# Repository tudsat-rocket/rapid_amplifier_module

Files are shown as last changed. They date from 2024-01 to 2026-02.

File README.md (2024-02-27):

# FRoDo Amplifier Module
this module is meant to be a general-purpose amplifier which is going to be used for all analogue sensors which will be in the rocket, those include the WIKA pressure sensors as well as the fancy-fins strain gauges.

## Description
The main function of the module is to amplify signals with low voltage levels that are too small to be useful for our ADCs. Therefore the board has two sides with solder pads, one to connect to the IO board and one to connect to a sensor. The layout is designed in a way, that the sensor side is compatible with the WIKA TPR-Flex PCBs.

## Features
* Selectable gain (1-1000) -> the selection of RG1 will determine the gain (G = 1 + 49,4kOhm/RG)
* selectable offset -> output offset can either be 0V or Vcc/2
* Breakaway mounting holes
## Connections
### To IO-Board:
Connects the amplifier module with the IO-Board with the following pins:
* u+  ->  positive supply voltage (3-36V)
* u-  ->  gnd as "neg" supply voltage (only use in single supply mode) | reference for the output signal.
* o+  ->  amplified signal, references gnd (u-)
* ref  ->  selected reference signal (0V or Vcc/2) can be used to get additional information (e.g. detect noise on supply line(?))

### To sensor:
Connects the amplifier module with the Sensor with the following pins:
* u+  -> positive supply voltage (filtered supply voltage)
* u-  -> neg. supply voltage (gnd)
* s+  -> positive signal
* s-  -> negative signal

## User guideline:
The Gain resistor (RG1) must be chosen in a way that the expected maximum amplified voltage is lower than 4.85V (5V - 0.15V) and the expected minimum amplified voltage is higher than 0.1V if a smaller (or negative) output voltage is expected the solder jumper for the reference voltage needs to be connected to 3 to set an output shift.
Only if the connected sensor is expected to output a signal which exclusively results in an output signal that is in the above given values, can the reference solder jumper be set to 1.

The above-given adjustments are necessary as the IO module is only able to read values between 0V and 5V. A higher Input voltage can be used if the connected sensor needs a supply voltage which exceeds 5V. The amplified signal then still needs to be smaller than the given 4.85V.

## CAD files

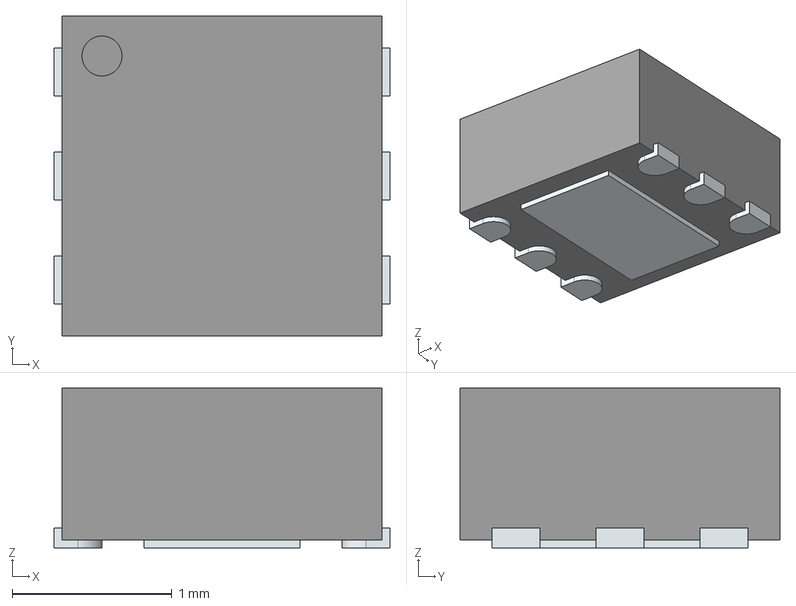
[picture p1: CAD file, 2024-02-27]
LDFM33PVR/3D/LDFM33PVR.stp
2.10 x 2.00 x 1.00 mm
ThermalPin
PinsArrayLR

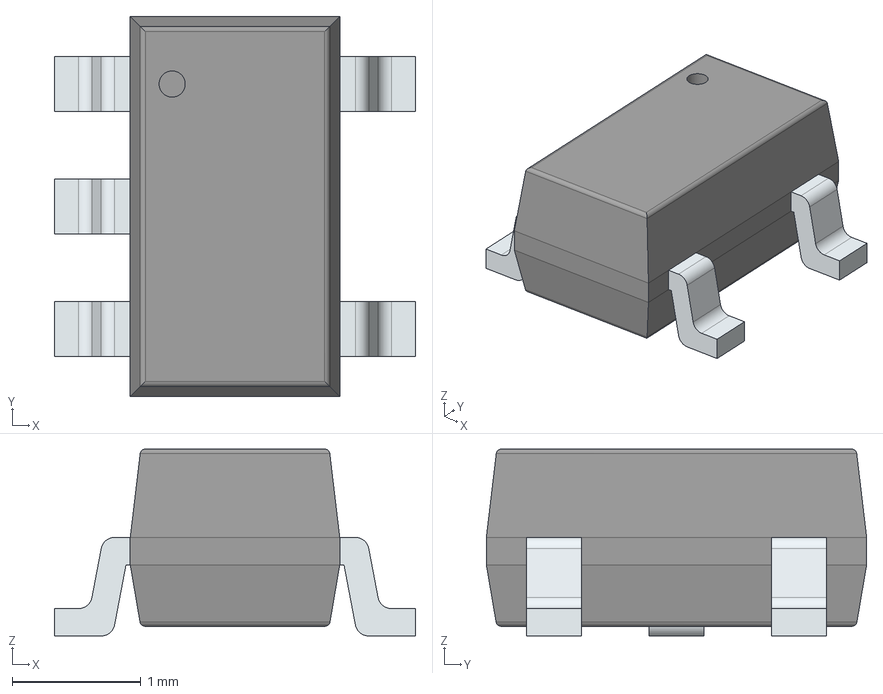
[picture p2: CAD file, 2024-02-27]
MCP3221A5T-I_OT/3D/MCP3221A5T-I_OT.stp
2.80 x 2.95 x 1.45 mm
PinsArrayL
PinsArrayR

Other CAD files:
LDFM33PVR/Allegro/son65p200x200x100-7n-d.psm
LDFM33PVR/DEHDL/ldfm33pvr/chips/chips.prt
MCP3221A5T-I_OT/Allegro/sot95p280x145-5n.psm
MCP3221A5T-I_OT/DEHDL/mcp3221a5t_i_ot/chips/chips.prt

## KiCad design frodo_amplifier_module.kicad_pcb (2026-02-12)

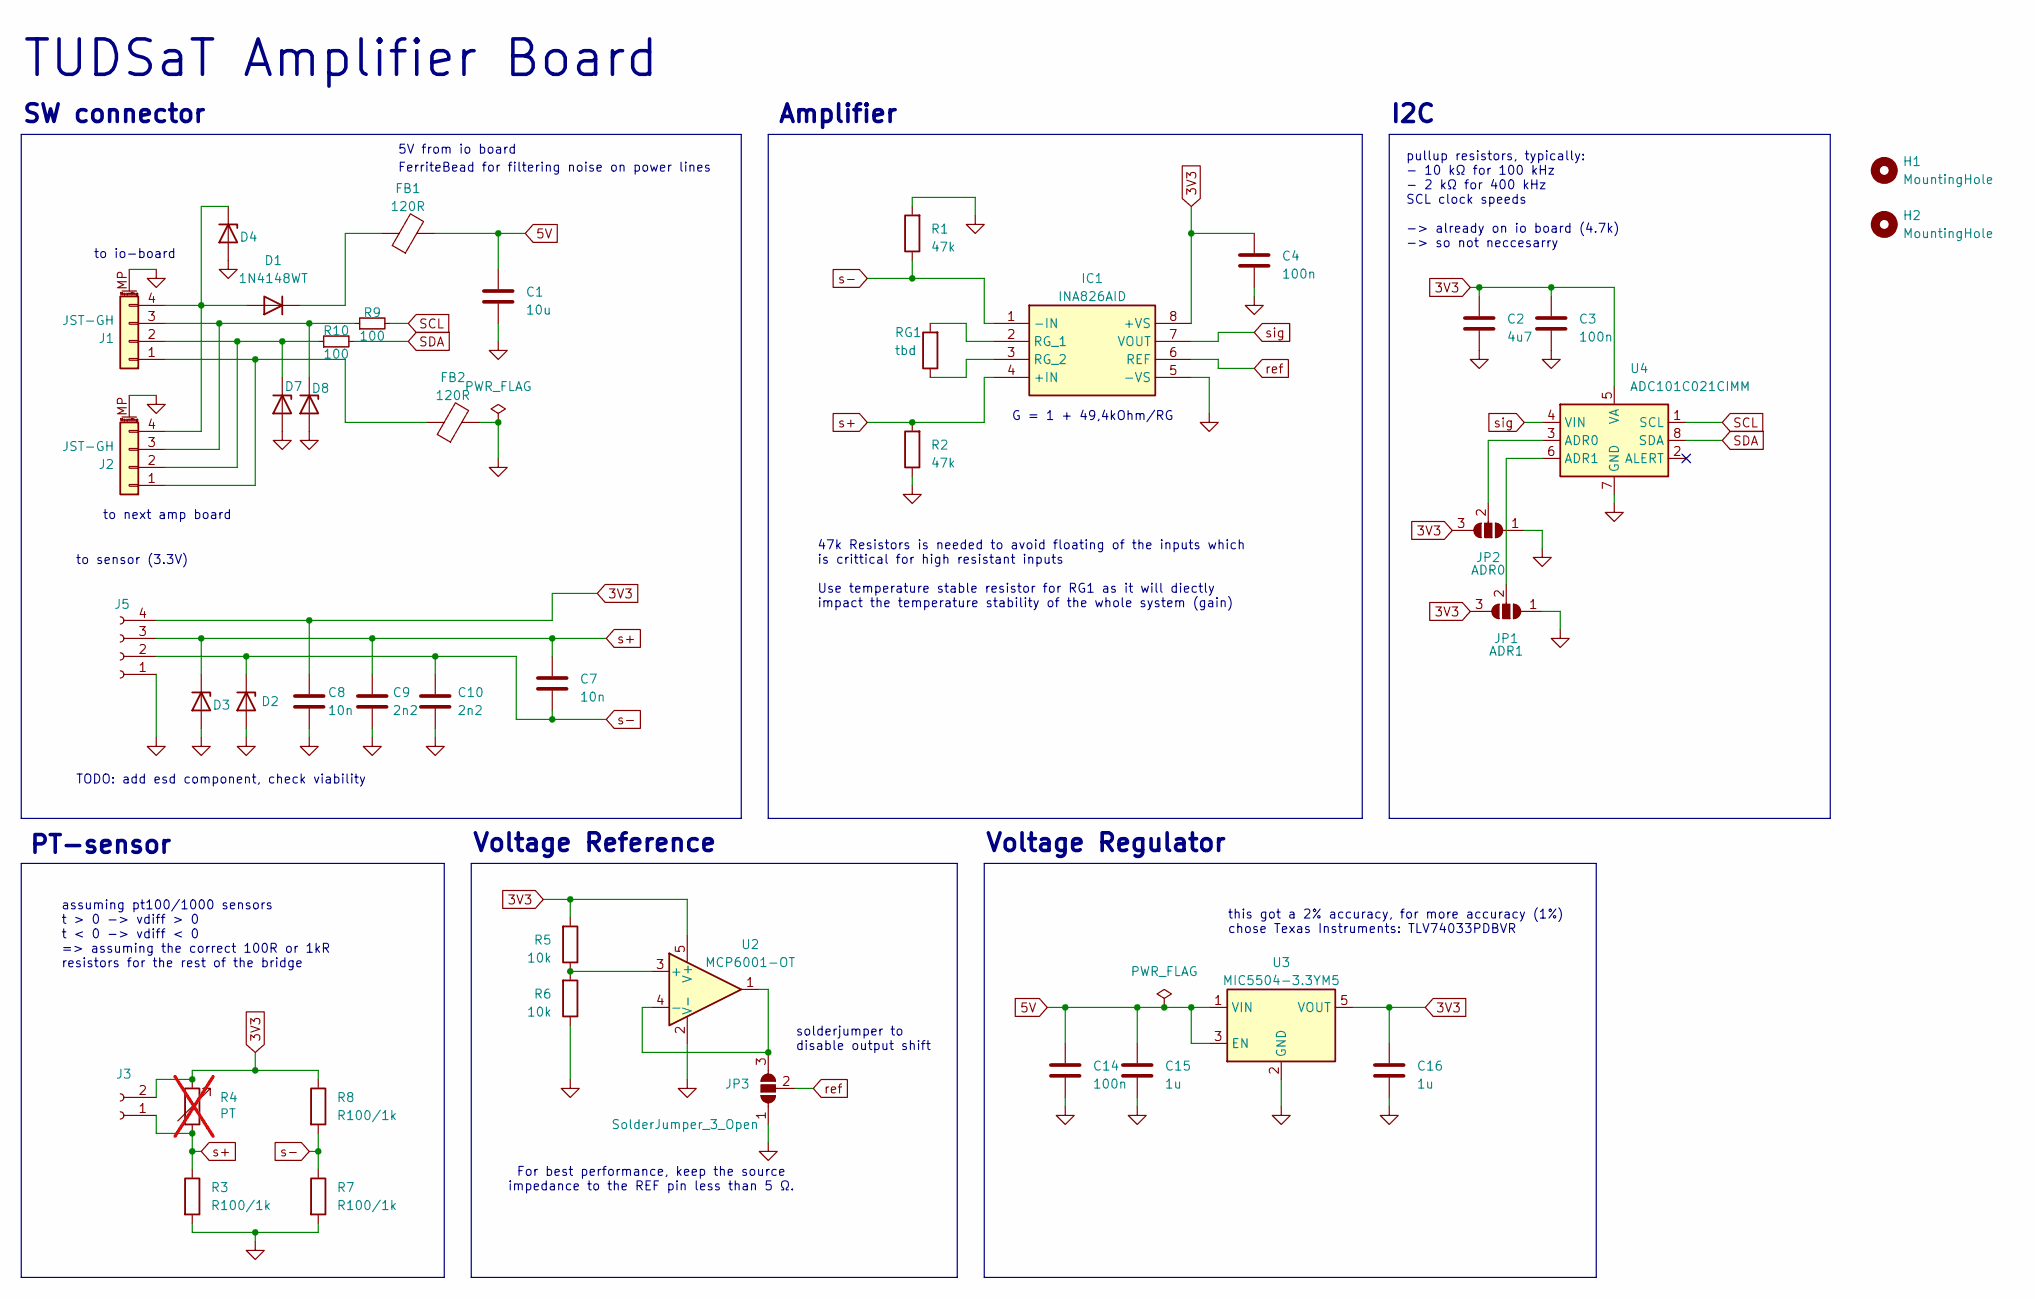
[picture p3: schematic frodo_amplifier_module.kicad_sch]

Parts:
C1: 10u; C_0402_1005Metric; LCSC C315248
C2: 4u7; C_0402_1005Metric; LCSC C23733
C3, C4, C14: 100n; C_0402_1005Metric; LCSC C1525
C7, C8: 10n; C_0402_1005Metric; LCSC C15195
C9, C10: 2n2; C_0402_1005Metric; LCSC C84703
C15, C16: 1u; C_0402_1005Metric; LCSC C76999
D1: 1N4148WT; D_SOD-523
D2, D3, D4, D7, D8: ESD5Zxx; D_SOD-523
FB1, FB2: 120R; L_0402_1005Metric; LCSC C76891
H1, H2: MountingHole; MountingHole_2.2mm_M2_DIN965_Pad
IC1: INA826AID; WSON-8-1EP_3x3mm_P0.5mm_EP1.2x2mm; Mouser Part Number 595-INA826AID
J1, J2: JST-GH; JST_GH_SM04B-GHS-TB_1x04-1MP_P1.25mm_Horizontal; Part# BM04B-GHS-TBT; LCSC C161692
J3: Conn_01x02_Socket; R_Axial_DIN0204_L3.6mm_D1.6mm_P1.90mm_Vertical
J5: Conn_01x04_Socket; PinHeader_1x04_P1.27mm_Vertical
JP1: ADR1; SolderJumper-3_P1.3mm_Open_RoundedPad1.0x1.5mm
JP2: ADR0; SolderJumper-3_P1.3mm_Open_RoundedPad1.0x1.5mm
JP3: SolderJumper_3_Open; SolderJumper-3_P1.3mm_Open_Pad1.0x1.5mm
R1: 47k; R_0402_1005Metric; LCSC C25792
R2: 47k; R_0402_1005Metric_Pad0.72x0.64mm_HandSolder; LCSC C25792
R3, R7, R8: R100/1k; R_0805_2012Metric_Pad1.20x1.40mm_HandSolder
R4: PT; not fitted
R5, R6: 10k; R_0402_1005Metric_Pad0.72x0.64mm_HandSolder; LCSC C25744
R9, R10: 100; R_0402_1005Metric; Part# RC0402FR-07100RL; LCSC# C106232
RG1: tbd; R_1206_3216Metric_Pad1.30x1.75mm_HandSolder
U2: MCP6001-OT; SOT-23-5; LCSC C116490
U3: MIC5504-3.3YM5; SOT-23-5; LCSC C3021093
U4: ADC101C021CIMM; MSOP-8_3x3mm_P0.65mm; LCSC C1543337

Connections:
3V3: C2.1, C3.1, C4.1, C8.1, C16.1, IC1.8 (+VS), J3.2, J5.4, JP1.3 (B), JP2.3 (B), R4.1, R5.2, R8.1, U2.5 (V+), U3.5 (VOUT), U4.5 (VA)
5V: C1.1, C14.1, C15.1, FB1.2, U3.1 (VIN), U3.3 (EN)
GND: C1.2, C2.2, C3.2, C4.2, C8.2, C9.2, C10.2, C14.2, C15.2, C16.2, D2.2 (A), D3.2 (A), D4.2 (A), D7.2 (A), D8.2 (A), FB2.2, IC1.5 (-VS), J1.MP (MountPin), J2.MP (MountPin), J5.1, JP1.1 (A), JP2.1 (A), JP3.1 (A), R1.2, R2.1, R3.2, R6.1, R7.2, U2.2 (V-), U3.2 (GND), U4.7 (GND)
unnamed: D1.2 (A), D4.1 (K), J1.4, J2.4
unnamed: D1.1 (K), FB1.1
unnamed: D7.1 (K), J1.2, J2.2, R10.1
unnamed: D8.1 (K), J1.3, J2.3, R9.1
unnamed: IC1.2 (RG_1), RG1.2
unnamed: IC1.3 (RG_2), RG1.1
unnamed: FB2.1, J1.1, J2.1
unnamed: JP1.2 (C), U4.6 (ADR1)
unnamed: JP2.2 (C), U4.3 (ADR0)
unnamed: JP3.3 (B), U2.1, U2.4 (-)
unnamed: R5.1, R6.2, U2.3 (+)
SCL: R9.2, U4.1 (SCL)
SDA: R10.2, U4.8 (SDA)
ref: IC1.6 (REF), JP3.2 (C)
s+: C7.1, C9.1, D3.1 (K), IC1.4 (+IN), J3.1, J5.3, R2.2, R3.1, R4.2
s-: C7.2, C10.1, D2.1 (K), IC1.1 (-IN), J5.2, R1.1, R7.1, R8.2
sig: IC1.7 (VOUT), U4.4 (VIN)

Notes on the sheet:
pullup resistors, typically: - 10 kΩ for 100 kHz - 2 kΩ for 400 kHz SCL clock speeds -> already on io board (4.7k) -> so not neccesarry
to sensor (3.3V)
G = 1 + 49,4kOhm/RG
SW connector
Voltage Regulator
to next amp board
TODO: add esd component, check viability
5V from io board
FerriteBead for filtering noise on power lines
solderjumper to disable output shift
TUDSaT Amplifier Board
Voltage Reference
47k Resistors is needed to avoid floating of the inputs which is crittical for high resistant inputs Use temperature stable resistor for RG1 as it will diectly impact the temperature stability of the whole system (gain)
I2C
assuming pt100/1000 sensors t > 0 -> vdiff > 0 t < 0 -> vdiff < 0 => assuming the correct 100R or 1kR resistors for the rest of the bridge
Amplifier
PT-sensor
this got a 2% accuracy, for more accuracy (1%) chose Texas Instruments: TLV74033PDBVR
to io-board
For best performance, keep the source impedance to the REF pin less than 5 Ω.

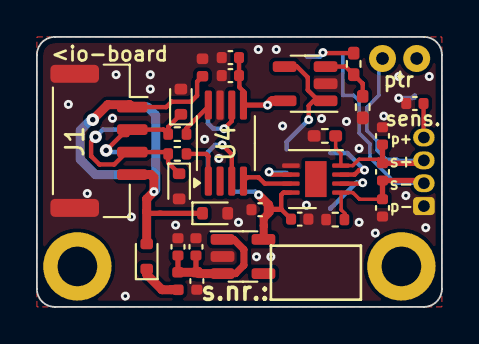
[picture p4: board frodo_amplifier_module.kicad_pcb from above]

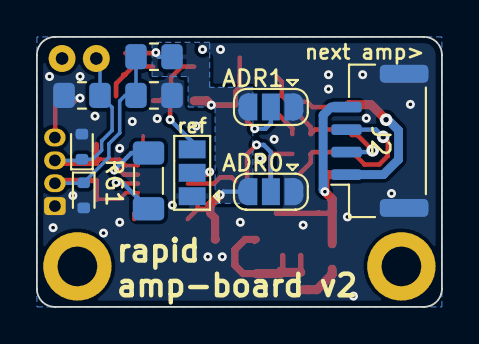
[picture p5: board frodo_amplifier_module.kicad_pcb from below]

Board: 4 copper layers, 22.5 x 15.0 mm, 42 parts (10 on the bottom side), 20 nets.

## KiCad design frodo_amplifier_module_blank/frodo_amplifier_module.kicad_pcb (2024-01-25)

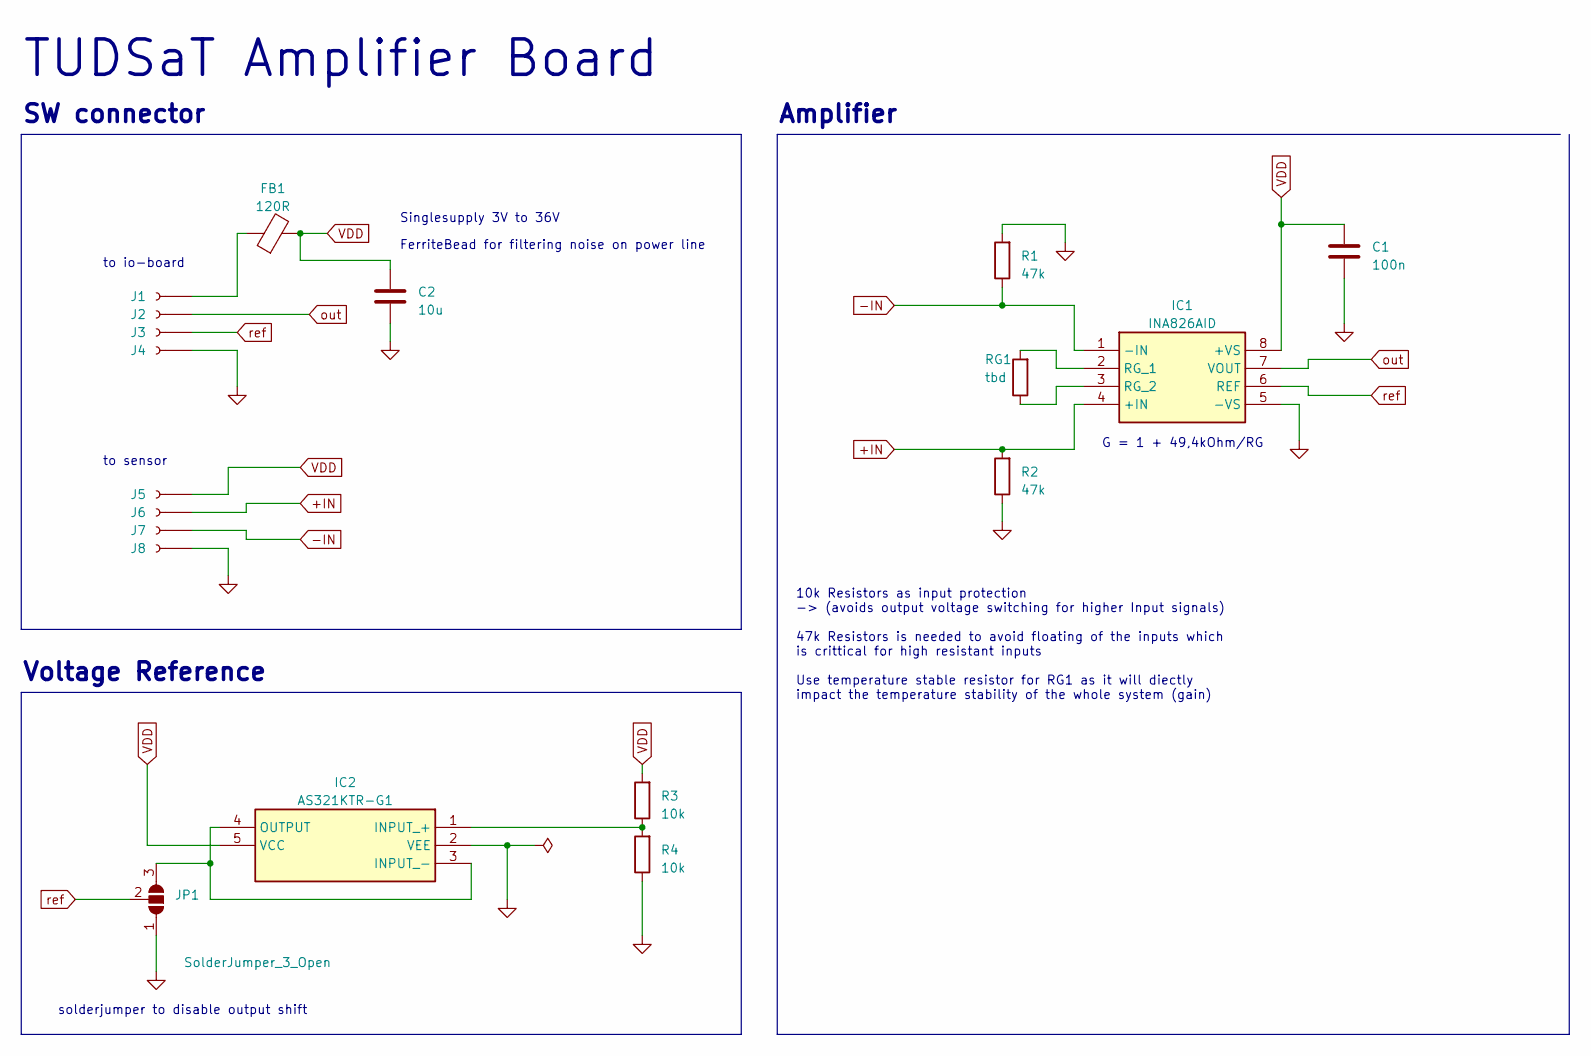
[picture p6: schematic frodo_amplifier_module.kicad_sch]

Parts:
C1: 100n; C_0402_1005Metric_Pad0.74x0.62mm_HandSolder
C2: 10u; C_0603_1608Metric
FB1: 120R; L_0603_1608Metric
IC1: INA826AID; SOIC-8_3.9x4.9mm_P1.27mm; Mouser Part Number 595-INA826AID
IC2: AS321KTR-G1; SOT-23-5; Mouser Part Number 621-AS321KTR-G1
J1, J2, J3, J4, J5, J6, J7, J8: Conn_01x01_Socket; SolderWirePad_1x01_SMD_1x2mm
JP1: SolderJumper_3_Open; SolderJumper-3_P1.3mm_Open_RoundedPad1.0x1.5mm_NumberLabels
R1, R2: 47k; R_0402_1005Metric_Pad0.72x0.64mm_HandSolder
R3, R4: 10k; R_0402_1005Metric_Pad0.72x0.64mm_HandSolder
RG1: tbd; R_0603_1608Metric_Pad0.98x0.95mm_HandSolder

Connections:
+IN: IC1.4 (+IN), J6.1, R2.2
-IN: IC1.1 (-IN), J7.1, R1.1
GND: C1.2, C2.2, IC1.5 (-VS), IC2.2 (VEE), J4.1, J8.1, JP1.1 (A), R1.2, R2.1, R4.1
unnamed: IC1.2 (RG_1), RG1.2
unnamed: IC1.3 (RG_2), RG1.1
unnamed: IC2.1 (INPUT_+), R3.1, R4.2
unnamed: IC2.3 (INPUT_-), IC2.4 (OUTPUT), JP1.3 (B)
unnamed: FB1.1, J1.1
VDD: C1.1, C2.1, FB1.2, IC1.8 (+VS), IC2.5 (VCC), J5.1, R3.2
out: IC1.7 (VOUT), J2.1
ref: IC1.6 (REF), J3.1, JP1.2 (C)

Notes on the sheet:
to sensor
G = 1 + 49,4kOhm/RG
SW connector
Singlesupply 3V to 36V
FerriteBead for filtering noise on power line
TUDSaT Amplifier Board
Voltage Reference
10k Resistors as input protection -> (avoids output voltage switching for higher Input signals) 47k Resistors is needed to avoid floating of the inputs which is crittical for high resistant inputs Use temperature stable resistor for RG1 as it will diectly impact the temperature stability of the who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
Amplifier
solderjumper to disable output shift
to io-board

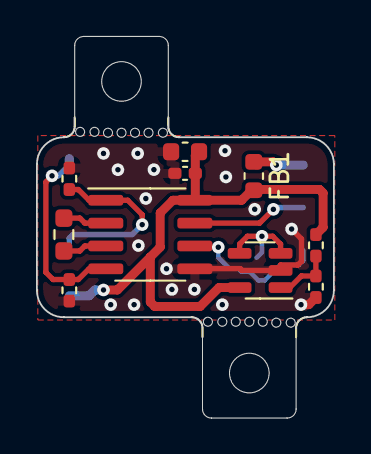
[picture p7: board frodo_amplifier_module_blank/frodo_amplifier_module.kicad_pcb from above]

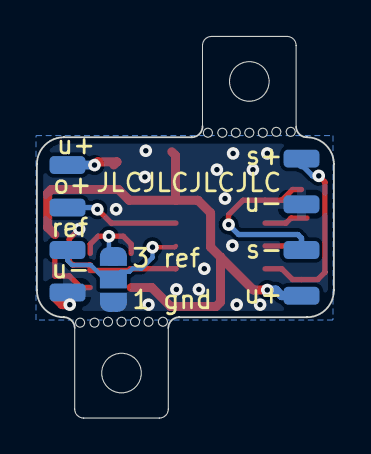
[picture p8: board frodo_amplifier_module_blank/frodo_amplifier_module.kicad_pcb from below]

Board: 2 copper layers, 16.5 x 21.2 mm, 21 parts (9 on the bottom side), 11 nets.

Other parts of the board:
mouse-bite-2mm-slot, mouse-bite-2mm-slot#2: VAL**; mouse-bite-2mm-slot

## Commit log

2024-01-09 Add files via upload
    sry Jesko, bekomm es grad nicht besser hin wir können da ma zusammen drüberschauen dass des mit den namen etc. alles passt.
    [verstärker.kicad_pcb, verstärker.kicad_sch]
2024-01-10 file structure cleanup
    [frodo_amplifier_module.kicad_pcb, frodo_amplifier_module.kicad_sch, verstärker.kicad_pcb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]
2024-01-16 updated amplifier module, removed mounting holes and routed the pcb
    [frodo_amplifier_module.kicad_pcb, frodo_amplifier_module.kicad_sch]
2024-01-18 updated stuff
    [frodo_amplifier_module.kicad_pcb, frodo_amplifier_module.kicad_sch]
2024-01-18 added stuff
    [frodo_amplifier_module.kicad_sch]
2024-01-20 fixed soulder jumper, added mousbites
    [frode_amplifier_module_mountingHoles.kicad_pcb, frodo_amplifier_module.kicad_pcb, frodo_amplifier_module.kicad_sch]
2024-01-21 fixed my messup
    [frode_amplifier_module_mountingHoles.kicad_pcb, frodo_amplifier_module.kicad_pcb, frodo_amplifier_module.kicad_sch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]
2024-01-24 updated mounting holes and footprints of c2 and fb1
    [frodo_amplifier_module.kicad_pcb, frodo_amplifier_module.kicad_sch, frodo_amplifier_module_mounting_hole.kicad_pcb]
2024-01-25 changed mounting holes
    [frodo_amplifier_module.kicad_pcb, frodo_amplifier_module_mounting_hole.kicad_pcb]
2024-01-29 changed folder layout, optimised gnd routing
    [frodo_amplifier_module.kicad_pcb, frodo_amplifier_module.kicad_sch]
2024-01-29 added silcscrean for better usability
    [frodo_amplifier_module.kicad_pcb]
2024-01-29 added silcscreen
    [frodo_amplifier_module.kicad_pcb]
2024-02-27 added kicad files
2024-02-27 started adding wika recomendations
    [EDI2CAP.CFG, LDFM33PVR.SchLib, LDFM33PVR.stp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]
2024-03-25 continued working on v0.2
    [frodo_amplifier_module.kicad_sch]
2024-03-26 implemented wikas recomendations to scematic
    [frodo_amplifier_module.kicad_sch]
2024-04-07 finished the scematics
    [frodo_amplifier_module.kicad_pcb, frodo_amplifier_module.kicad_sch]
2024-04-07 started the pcb layout for the amp module
    [frodo_amplifier_module.kicad_pcb, frodo_amplifier_module.kicad_sch]
2024-04-14 finished pcb layout - routing not done yet
    [frodo_amplifier_module.kicad_pcb, frodo_amplifier_module.kicad_sch]
2024-04-20 finished routing -> pcb should be ready to order after review
    [frodo_amplifier_module.kicad_pcb]
2024-05-20 optimised via placement
    [frodo_amplifier_module.kicad_pcb, frodo_amplifier_module.kicad_sch]
2024-07-04 fixed silkscreen
    [frodo_amplifier_module.kicad_pcb]
2024-07-04 remove 3v3ref, merge fills, adjust layout, fill BOM
    [frodo_amplifier_module.kicad_pcb, frodo_amplifier_module.kicad_sch]
2026-02-03 finished amp module rev3
    [frodo_amplifier_module.kicad_pcb, frodo_amplifier_module.kicad_sch]
2026-02-12 fixed design errors in amp board
    [frodo_amplifier_module.kicad_pcb, frodo_amplifier_module.kicad_sch]
2026-02-16 did kicad design checks and adjusted design accordingly
